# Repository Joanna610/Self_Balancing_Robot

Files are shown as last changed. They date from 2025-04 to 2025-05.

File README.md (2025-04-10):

# Self_Balancing_Robot

The projects include code for Arduino. It collects data from the acceleromiter MPU6050 and modifies them accordingly. The code also turn on and off the motors with PWM. It can do this thanks to H bridge - L293D. The robot try to stabilize itself due to implemented PID algorithm.

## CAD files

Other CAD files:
construction/Self_balancing_robot.ipt

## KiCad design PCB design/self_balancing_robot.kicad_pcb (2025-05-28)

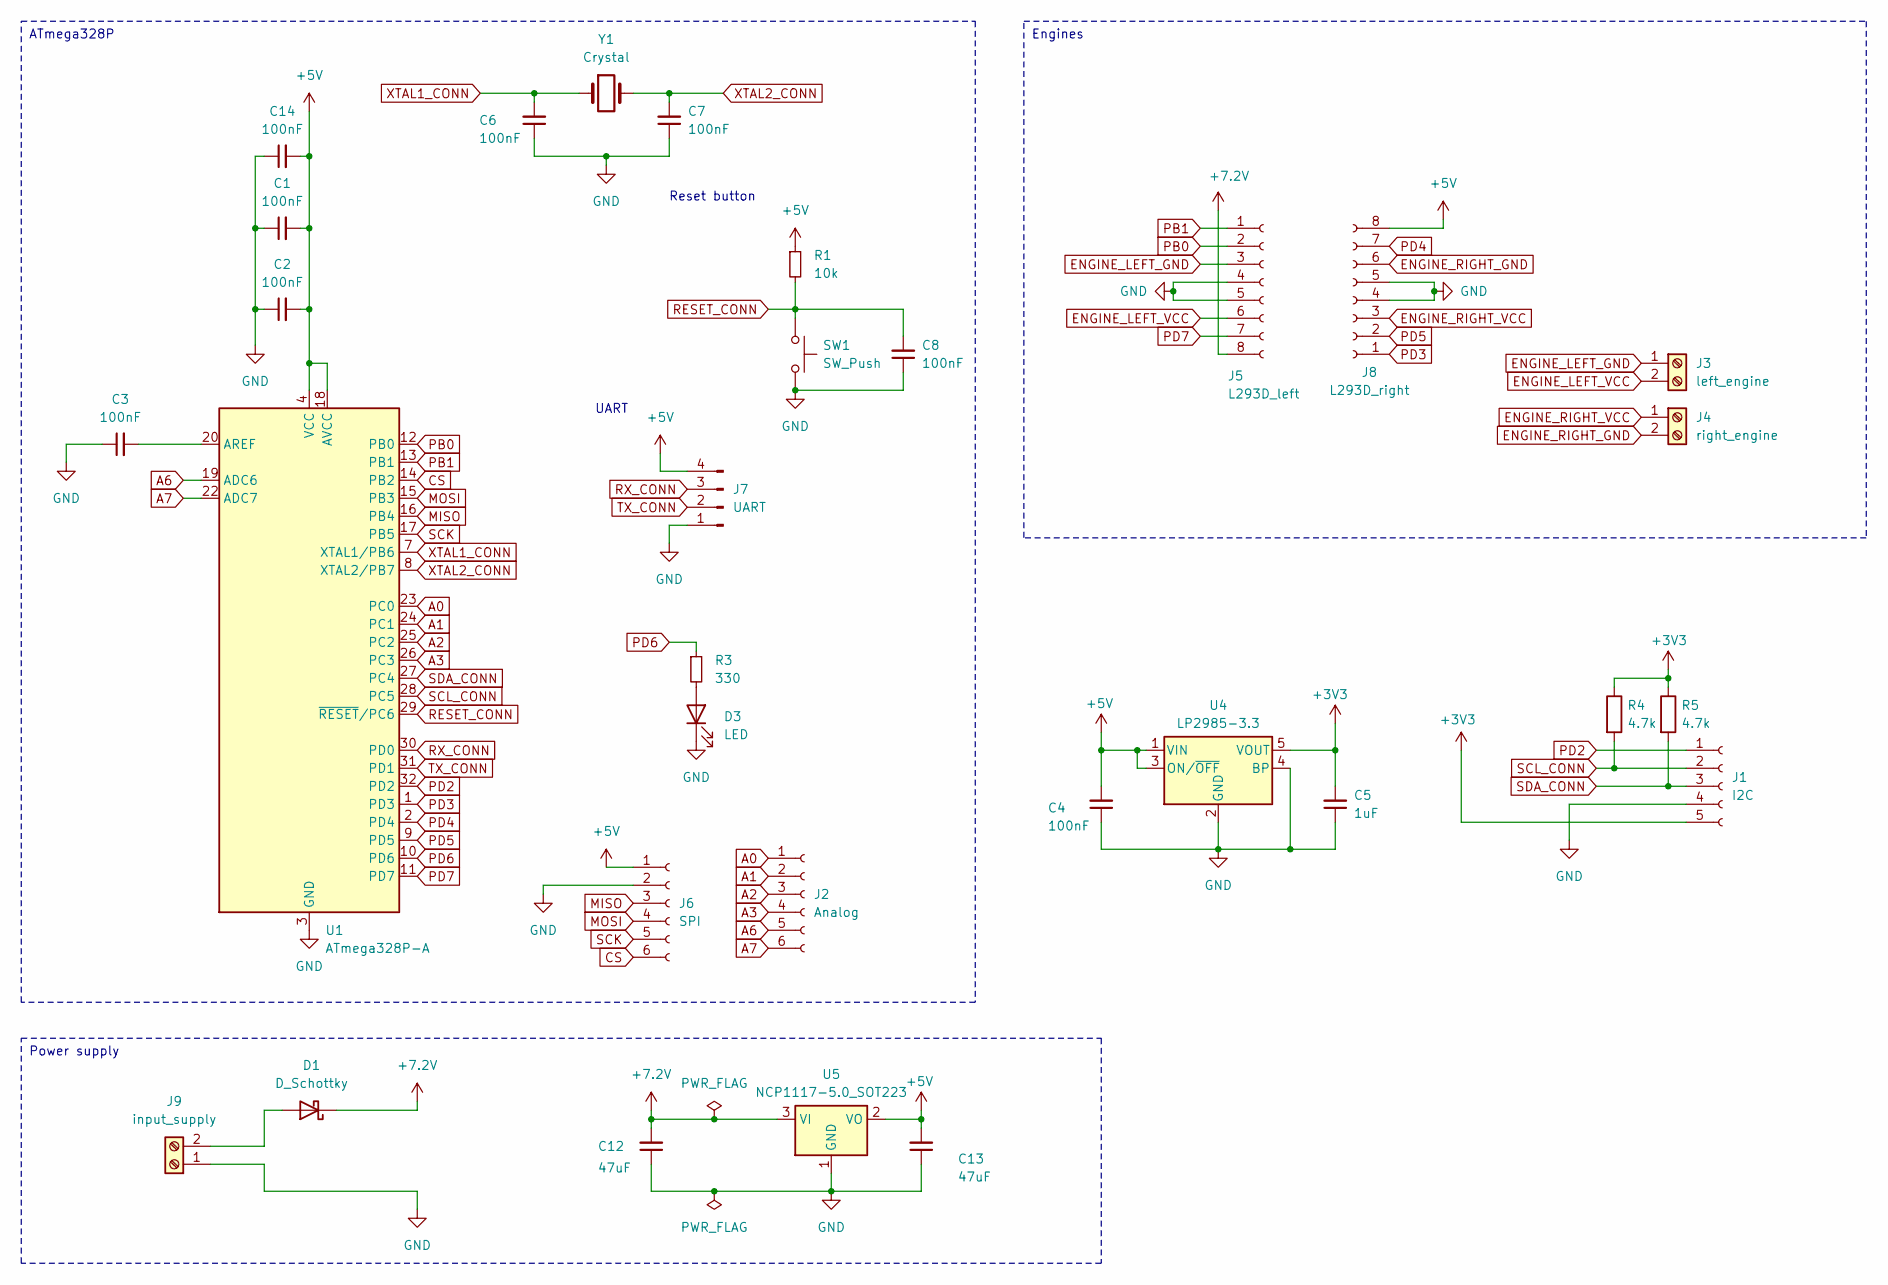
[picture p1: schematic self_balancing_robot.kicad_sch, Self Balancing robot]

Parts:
C1, C2, C3, C4, C6, C7, C8, C14: 100nF; C_0805_2012Metric
C5: 1uF; C_0805_2012Metric
C12, C13: 47uF; C_0805_2012Metric
D1: D_Schottky; R_Axial_DIN0207_L6.3mm_D2.5mm_P7.62mm_Horizontal
D3: LED; LED_1206_3216Metric
J1: I2C; PinSocket_1x05_P2.54mm_Vertical
J2: Analog; PinSocket_1x06_P2.54mm_Vertical
J3: left_engine; TE_826576-2_1x02_P3.96mm_Vertical
J4: right_engine; TE_826576-2_1x02_P3.96mm_Vertical
J5: L293D_left; PinSocket_1x08_P2.54mm_Vertical
J6: SPI; PinSocket_1x06_P2.54mm_Vertical
J7: UART; PinHeader_1x04_P2.54mm_Vertical
J8: L293D_right; PinSocket_1x08_P2.54mm_Vertical
J9: input_supply; TE_826576-2_1x02_P3.96mm_Vertical
R1: 10k; R_0805_2012Metric
R3: 330; R_0805_2012Metric
R4, R5: 4.7k; R_0805_2012Metric
SW1: SW_Push; SW_PUSH_1P1T_6x3.5mm_H5.0_APEM_MJTP1250
U1: ATmega328P-A; TQFP-32_7x7mm_P0.8mm
U4: LP2985-3.3; SOT-23-5
U5: NCP1117-5.0_SOT223; SOT-223-3_TabPin2
Y1: Crystal; Crystal_HC49-4H_Vertical

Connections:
+3V3: C5.2, J1.5, R4.1, R5.1, U4.5 (VOUT)
+5V: C1.2, C2.2, C4.2, C13.2, C14.2, J6.1, J7.4, J8.8, R1.1, U1.4 (VCC), U1.6 (VCC), U1.18 (AVCC), U4.1 (VIN), U4.3 (ON/~OFF), U5.2 (VO)
+7.2V: C12.2, D1.1 (K), J5.8, U5.3 (VI)
A0: J2.1, U1.23 (PC0)
A1: J2.2, U1.24 (PC1)
A2: J2.3, U1.25 (PC2)
A3: J2.4, U1.26 (PC3)
A6: J2.5, U1.19 (ADC6)
A7: J2.6, U1.22 (ADC7)
CS: J6.6, U1.14 (PB2)
ENGINE_LEFT_GND: J3.1, J5.3
ENGINE_LEFT_VCC: J3.2, J5.6
ENGINE_RIGHT_GND: J4.2, J8.6
ENGINE_RIGHT_VCC: J4.1, J8.3
GND: C1.1, C2.1, C3.1, C4.1, C5.1, C6.1, C7.1, C8.1, C12.1, C13.1, C14.1, D3.1 (K), J1.4, J5.4, J5.5, J6.2, J7.1, J8.4, J8.5, J9.1, SW1.2, U1.3 (GND), U1.5 (GND), U1.21 (GND), U4.2 (GND), U4.4 (BP), U5.1 (GND)
MISO: J6.3, U1.16 (PB4)
MOSI: J6.4, U1.15 (PB3)
unnamed: D1.2 (A), J9.2
unnamed: D3.2 (A), R3.2
unnamed: C3.2, U1.20 (AREF)
PB0: J5.2, U1.12 (PB0)
PB1: J5.1, U1.13 (PB1)
PD2: J1.1, U1.32 (PD2)
PD3: J8.1, U1.1 (PD3)
PD4: J8.7, U1.2 (PD4)
PD5: J8.2, U1.9 (PD5)
PD6: R3.1, U1.10 (PD6)
PD7: J5.7, U1.11 (PD7)
RESET_CONN: C8.2, R1.2, SW1.1, U1.29 (~RESET/PC6)
RX_CONN: J7.3, U1.30 (PD0)
SCK: J6.5, U1.17 (PB5)
SCL_CONN: J1.2, R4.2, U1.28 (PC5)
SDA_CONN: J1.3, R5.2, U1.27 (PC4)
TX_CONN: J7.2, U1.31 (PD1)
XTAL1_CONN: C6.2, U1.7 (XTAL1/PB6), Y1.1
XTAL2_CONN: C7.2, U1.8 (XTAL2/PB7), Y1.2

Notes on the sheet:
Engines
ATmega328P
Power supply
UART
Reset button

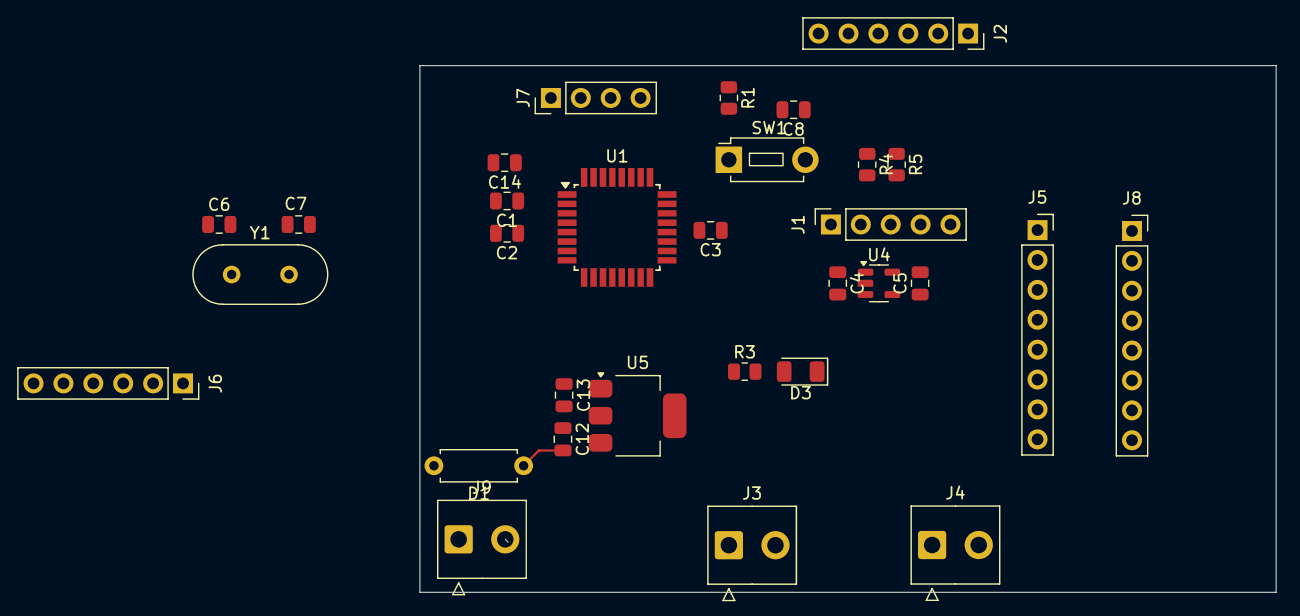
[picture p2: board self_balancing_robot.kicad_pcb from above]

Board: 2 copper layers, 72.8 x 44.8 mm, 31 parts (0 on the bottom side), 36 nets.

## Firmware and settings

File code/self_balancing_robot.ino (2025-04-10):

//https://lastminuteengineers.com/l293d-dc-motor-arduino-tutorial/

#include "I2Cdev.h"
#include "MPU6050.h"
#include <math.h>
// #include <Kalman.h>

#define OUTPUT_READABLE_ACCELGYRO

MPU6050 mpu;
// Kalman_h kal(0.001, 0.003, 0.03);

int16_t ax, ay, az;
int16_t gx, gy, gz;
float ax_, ay_, az_;

// Motor A connections
int enA = 9;
int in1 = 8;
int in2 = 7;
// Motor B connections
int enB = 3;
int in3 = 5;
int in4 = 4;

//PID
float kp = 8;
float ki = 0.1;
float kd = 0.075;


float pid_p = 0;
float pid_i = 0;
float pid_d = 0;

int16_t  targetAngle = 40, error, PID, previousError,  Speed = 100;

float time, timePrev, elapsedTime;
float accPitch, kalPitch;

// Filtr Kalmana - zmienne stanu
float angle = 0; // oszacowany kąt
float bias = 0;  // bias żyroskopu
float P[2][2] = {{1, 0}, {0, 1}}; // macierz błędu

// Parametry filtru
float Q_angle = 0.001;  // Niepewność modelu kąta
float Q_bias = 0.003;   // Niepewność biasu żyroskopu
float R_measure = 0.03; // Niepewność pomiaru akcelerometru

float K[2]; // Wzmocnienia Kalmana
float y;    // Różnica pomiaru
float S;    // Szacowana niepewność

float gyroRate, filteredAngle;

float KalmanFilter(float newAngle, float newRate, float dt) {
    // Przewidywanie (Prediction)
    angle += dt * (newRate - bias);
    P[0][0] += dt * (dt * P[1][1] - P[0][1] - P[1][0] + Q_angle);
    P[0][1] -= dt * P[1][1];
    P[1][0] -= dt * P[1][1];
    P[1][1] += Q_bias * dt;

    // Aktualizacja (Correction)
    S = P[0][0] + R_measure;
    K[0] = P[0][0] / S;
    K[1] = P[1][0] / S;

    y = newAngle - angle;
    angle += K[0] * y;
    bias += K[1] * y;

    P[0][0] -= K[0] * P[0][0];
    P[0][1] -= K[0] * P[0][1];
    P[1][0] -= K[1] * P[0][0];
    P[1][1] -= K[1] * P[0][1];

    return angle;
}

void Forwards()
{
  analogWrite(enA, Speed);
	analogWrite(enB, Speed);
  digitalWrite(in1, HIGH);
  digitalWrite(in2, LOW);
  digitalWrite(in3, HIGH);
  digitalWrite(in4, LOW);
  
}

void Backwards()
{
  analogWrite(enA, Speed);
	analogWrite(enB, Speed);
  digitalWrite(in1, LOW);
  digitalWrite(in2, HIGH);
  digitalWrite(in3, LOW);
  digitalWrite(in4, HIGH);
  
}

void Stop()
{
  digitalWrite(in1, LOW);
  digitalWrite(in2, LOW);
  digitalWrite(in3, LOW);
  digitalWrite(in4, LOW);
  analogWrite(enA, 0);
	analogWrite(enB, 0);
}

void setup() {
  #if I2CDEV_IMPLEMENTATION == I2CDEV_ARDUINO_WIRE
    Wire.begin(); 
  #elif I2CDEV_IMPLEMENTATION == I2CDEV_BUILTIN_FASTWIRE
    Fastwire::setup(400, true);
  #endif

  Serial.begin(115200);
  mpu.initialize();
  if(mpu.testConnection() ==  false){
    Serial.println("MPU6050 connection failed");
    while(true);
  }

  mpu.setXAccelOffset(0); //Set your accelerometer offset for axis X
  mpu.setYAccelOffset(0); //Set your accelerometer offset for axis Y
  mpu.setZAccelOffset(0); //Set your accelerometer offset for axis Z
  mpu.setXGyroOffset(0);  //Set your gyro offset for axis X
  mpu.setYGyroOffset(0);  //Set your gyro offset for axis Y
  mpu.setZGyroOffset(0);  //Set your gyro offset for axis Z
 
	// Set all the motor control pins to outputs
	pinMode(enA, OUTPUT);
	pinMode(enB, OUTPUT);
	pinMode(in1, OUTPUT);
	pinMode(in2, OUTPUT);
	pinMode(in3, OUTPUT);
	pinMode(in4, OUTPUT);
	
	// Turn off motors - Initial state
	digitalWrite(in1, LOW);
	digitalWrite(in2, LOW);
	digitalWrite(in3, LOW);
	digitalWrite(in4, LOW);
}



void loop() {

  timePrev = time;
  time = millis();
  elapsedTime = (time - timePrev) / 1000;

  mpu.getMotion6(&ax, &ay, &az, &gx, &gy, &gz);
  //mpu.getAcceleration(&ax, &ay, &az);
  //mpu.getRotation(&gx, &gy, &gz);

  ax_ = ax / 16384.0; // dla ±2g
  ay_ = ay / 16384.0;
  az_ = az / 16384.0;

  /*Print the obtained data on the defined format*/
  accPitch = atan2(ay_, sqrt(ax_ * ax_ + az_ * az_)) * 180.0 / M_PI;
  gyroRate = gx / 131.0; // Konwersja surowych danych żyroskopu (dla zakresu ±250°/s)
  filteredAngle = KalmanFilter(accPitch, gyroRate, elapsedTime);


  error = (int16_t)filteredAngle - targetAngle;

  //Proportional Error
  pid_p = kp * error;

  //Integral Error
  pid_i += (ki * error);

  //Differential Error
  pid_d = kd * ((error - previousError) / elapsedTime);

  //Total PID Value
  PID = pid_p + pid_i + pid_d;
  

  //Get modulous of PID value for speed of motors
  Speed = max(abs(PID) , 50);
  Speed = min(abs(PID) , 255);


  previousError = error;

  if (filteredAngle > 40)
  {Forwards();}
  
  if (filteredAngle < 40)
  {Backwards();} 

  if (filteredAngle < 20 || filteredAngle > 55)
  {Stop();} 


}

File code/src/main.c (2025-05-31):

#define FOSC 16000000
#define BAUD 9600

#define F_CPU 16000000UL

#include <inttypes.h>
#include <stdint.h>
#include <avr/io.h>
#include <util/delay.h>
#include <util/setbaud.h>
#include <math.h>
#include <avr/interrupt.h>

#include "mpu6050.h"
#include "mpu6050_reg.h"
#include "i2c.h"
#include "uart.h"
#include "KalmanFilter.h"
#include "engines.h"

#include <stdlib.h> 

int max_int(int a, int b) {
	if (a>b) return a;
    return b;
}

int min(int a, int b) {
    return (a < b) ? a : b;
}

void timer_setup();
//uint32_t get_time();
void get_time(double * dt);
volatile double count;

int main(void){
	SerialInit(FOSC, BAUD, 8, 2, 0);

	

	sei();  
	i2c_init();
	_delay_ms(200);

	int16_t accel_buff[3], gyro_buff[3];
	double accelX, accelY, accelZ, gyroY;
	double accPitch; // odchylenie
	double dt;
	int speed;

	double error, prev_error = 0;
	double pid_p, pid_i = 0, pid_d, pid;

	float kp = 40;
	float kd = 0.05;
	float ki = 200;
	

	uint8_t ret = i2c_start(MPU6050_ADDRESS+I2C_WRITE);
	if (ret == 1) SerialPrint("I2C cannot initialize!");
	else SerialPrint("I2C initialized :)\r\n");

	KalmanFilter kalman;
	initKalmanFilter(&kalman, 0.001, 0.003, 0.03);

	mpu6050_init();
	timer_setup();

	initEngines();

	while(1){
		get_time(&dt);

		mpu6050_read_accel_ALL(accel_buff);
		mpu6050_read_gyro_ALL(gyro_buff);

		accelX = accel_buff[0]*9.8*2/32768;
		accelY = accel_buff[1]*9.8*2/32768;
		accelZ = accel_buff[2]*9.8*2/32768;
		gyroY = (gyro_buff[1] / 131.0) * (M_PI / 180.0);

		accPitch = -(atan2(accelX, sqrt(accelY*accelY + accelZ*accelZ))*180.0)/M_PI;
		update(&kalman, accPitch, gyroY, dt);

		
		
		error = kalman.K_angle;

		//Proportional Error
		pid_p = kp * error;

		//Integral Error
		pid_i += (ki * error);

		//Differential Error
		pid_d = kd * ((error - prev_error) / dt);

		//Total PID Value
		pid = pid_p + pid_i + pid_d;

		prev_error = error;
		pid = abs(pid);
		//speed = max(abs((int)pid) , 50);
		speed = (int)abs(pid);
		if (speed < 100) speed = 100;
		if (speed > 255) speed = 255;
		
			SerialPrintInt(speed);
			SerialPrint("\r\n");
		if (error < -3) {
			forward(speed);
		} else if (error > 3) {
			backward(speed);
		} else {
			stop();
		}
			

		if (error < -90 || error > 90) {
			stop();
		}
	}
		
}

void timer_setup(){
    TCCR1A = 0x00;
    TIMSK1 |= _BV(TOIE1);
    TCCR1B |= _BV(CS10); // preskaler = 1 (16 MHz / 65536 ~ 244 Hz)
    TCCR1B &= ~( _BV(CS12)  | _BV(CS11));
}


void get_time(double * dt){
	cli();
		uint8_t l = TCNT1L;
		uint8_t h = TCNT1H;
		uint16_t step = h<<8 | l;
		*dt = (double)step / 16000000.0 + count * (65536.0 / 16000000.0);
		count = 0;
		TCNT1 = 0;
	sei();
}


// timer 1 overflow interrupt handler
SIGNAL(TIMER1_OVF_vect){
	count += 1;
	//TCNT1H = 0x00;
	//TCNT1L = 0x00;

}

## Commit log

2025-05-14 First PCB model attempt
    [self_balancing_robot.kicad_pcb, self_balancing_robot.kicad_sch]
2025-05-16 PCB update
    [self_balancing_robot.kicad_sch]
2025-05-28 PCB update - almost finishing
    [self_balancing_robot.kicad_pcb, self_balancing_robot.kicad_sch]
2025-05-31 code update - PID tunning
2025-06-30 The first stage of construction
    [Self_balancing_robot.ipt]
